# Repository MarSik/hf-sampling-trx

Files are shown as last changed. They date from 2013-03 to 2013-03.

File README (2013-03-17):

HF RX based on QSD and class E TX
---------------------------------

Important components:

Si570 - any frequency I2C controlled square wave oscillator
74CBT(LV)3253 - dual 1:4 analog multiplexor
LT6231CS8 - ultra low noise (1.1nV/sqrtHz) opamp
ATXmega128A3U - 8bit micro with dual ADC and DAC
XC9572XL - CPLD, programmable logic, 3.3V

References:

- Dan Tayloe, N7VE
  Ultra Low Noise, High Performance, Zero IF Quadrature Product Detector and Preamplifier
  http://www.norcalqrp.org/files/Tayloe_mixer_x3a.pdf

- Gerald Youngblood, AC5OG
  A Software-Defined Radio for the Masses
  http://www.flex-radio.com/data/doc/qex1.pdf
  http://www.flex-radio.com/data/doc/qex2.pdf
  http://www.flex-radio.com/data/doc/qex3.pdf
  http://www.flex-radio.com/data/doc/qex4.pdf

- YU1LM
  HF - 6m band pass filters
  http://yu1lm.qrpradio.com/HF-6m%20BP%20YU1LM%20ver2.pdf

- Dan Tayloe, N7VE
  Class E Amplifiers - NorCal QRP Club
  http://www.norcalqrp.org/files/class_e_amplifiers.pdf

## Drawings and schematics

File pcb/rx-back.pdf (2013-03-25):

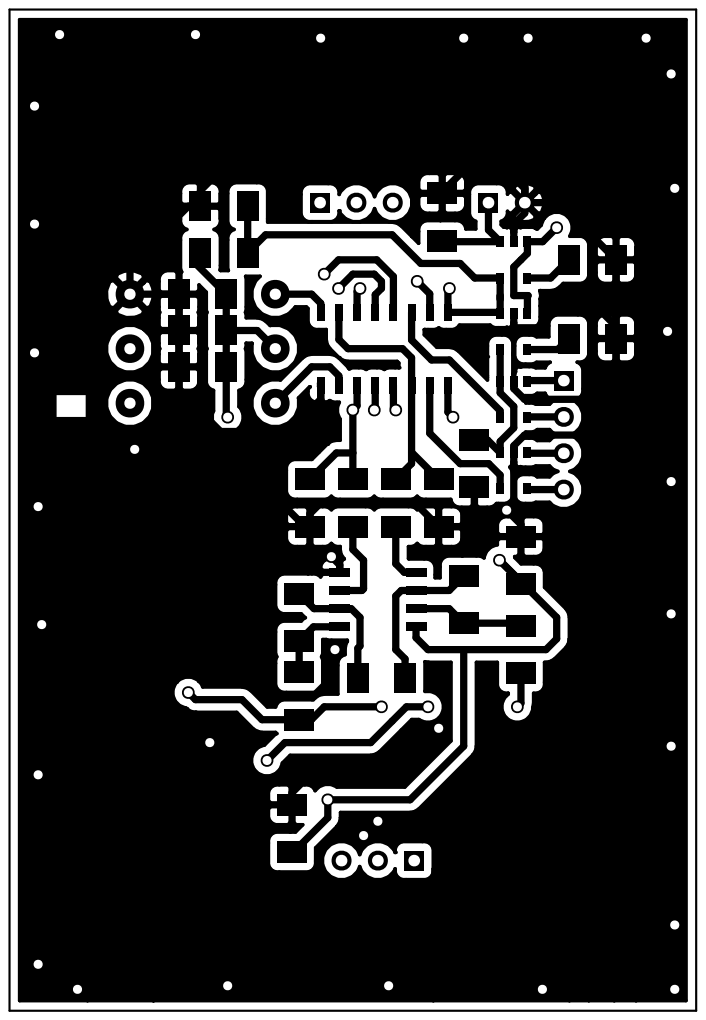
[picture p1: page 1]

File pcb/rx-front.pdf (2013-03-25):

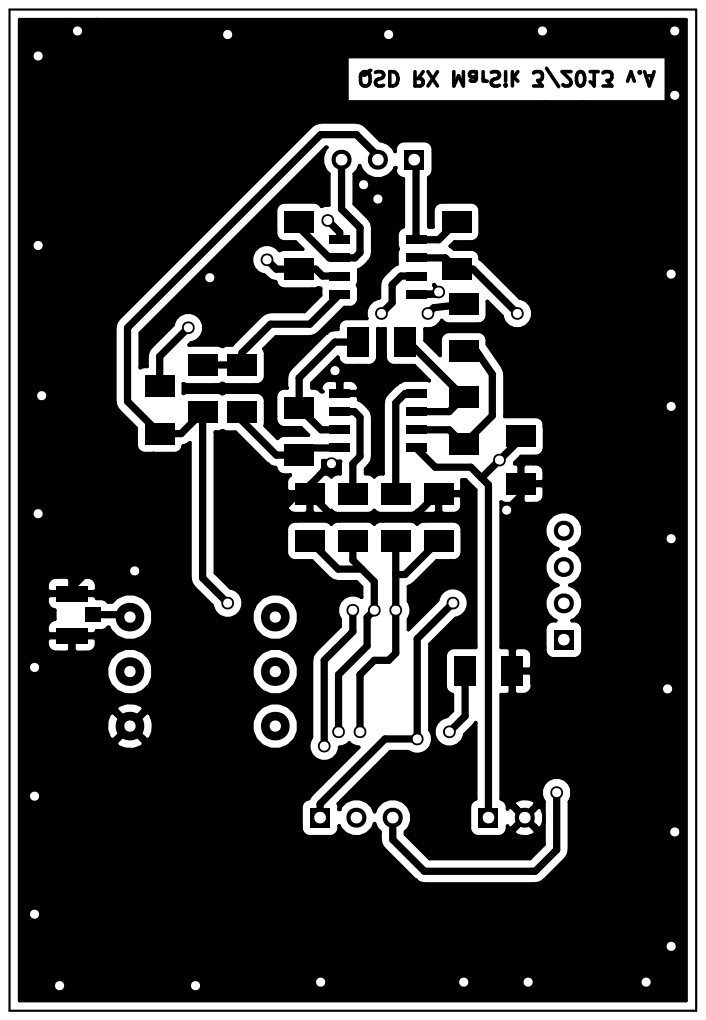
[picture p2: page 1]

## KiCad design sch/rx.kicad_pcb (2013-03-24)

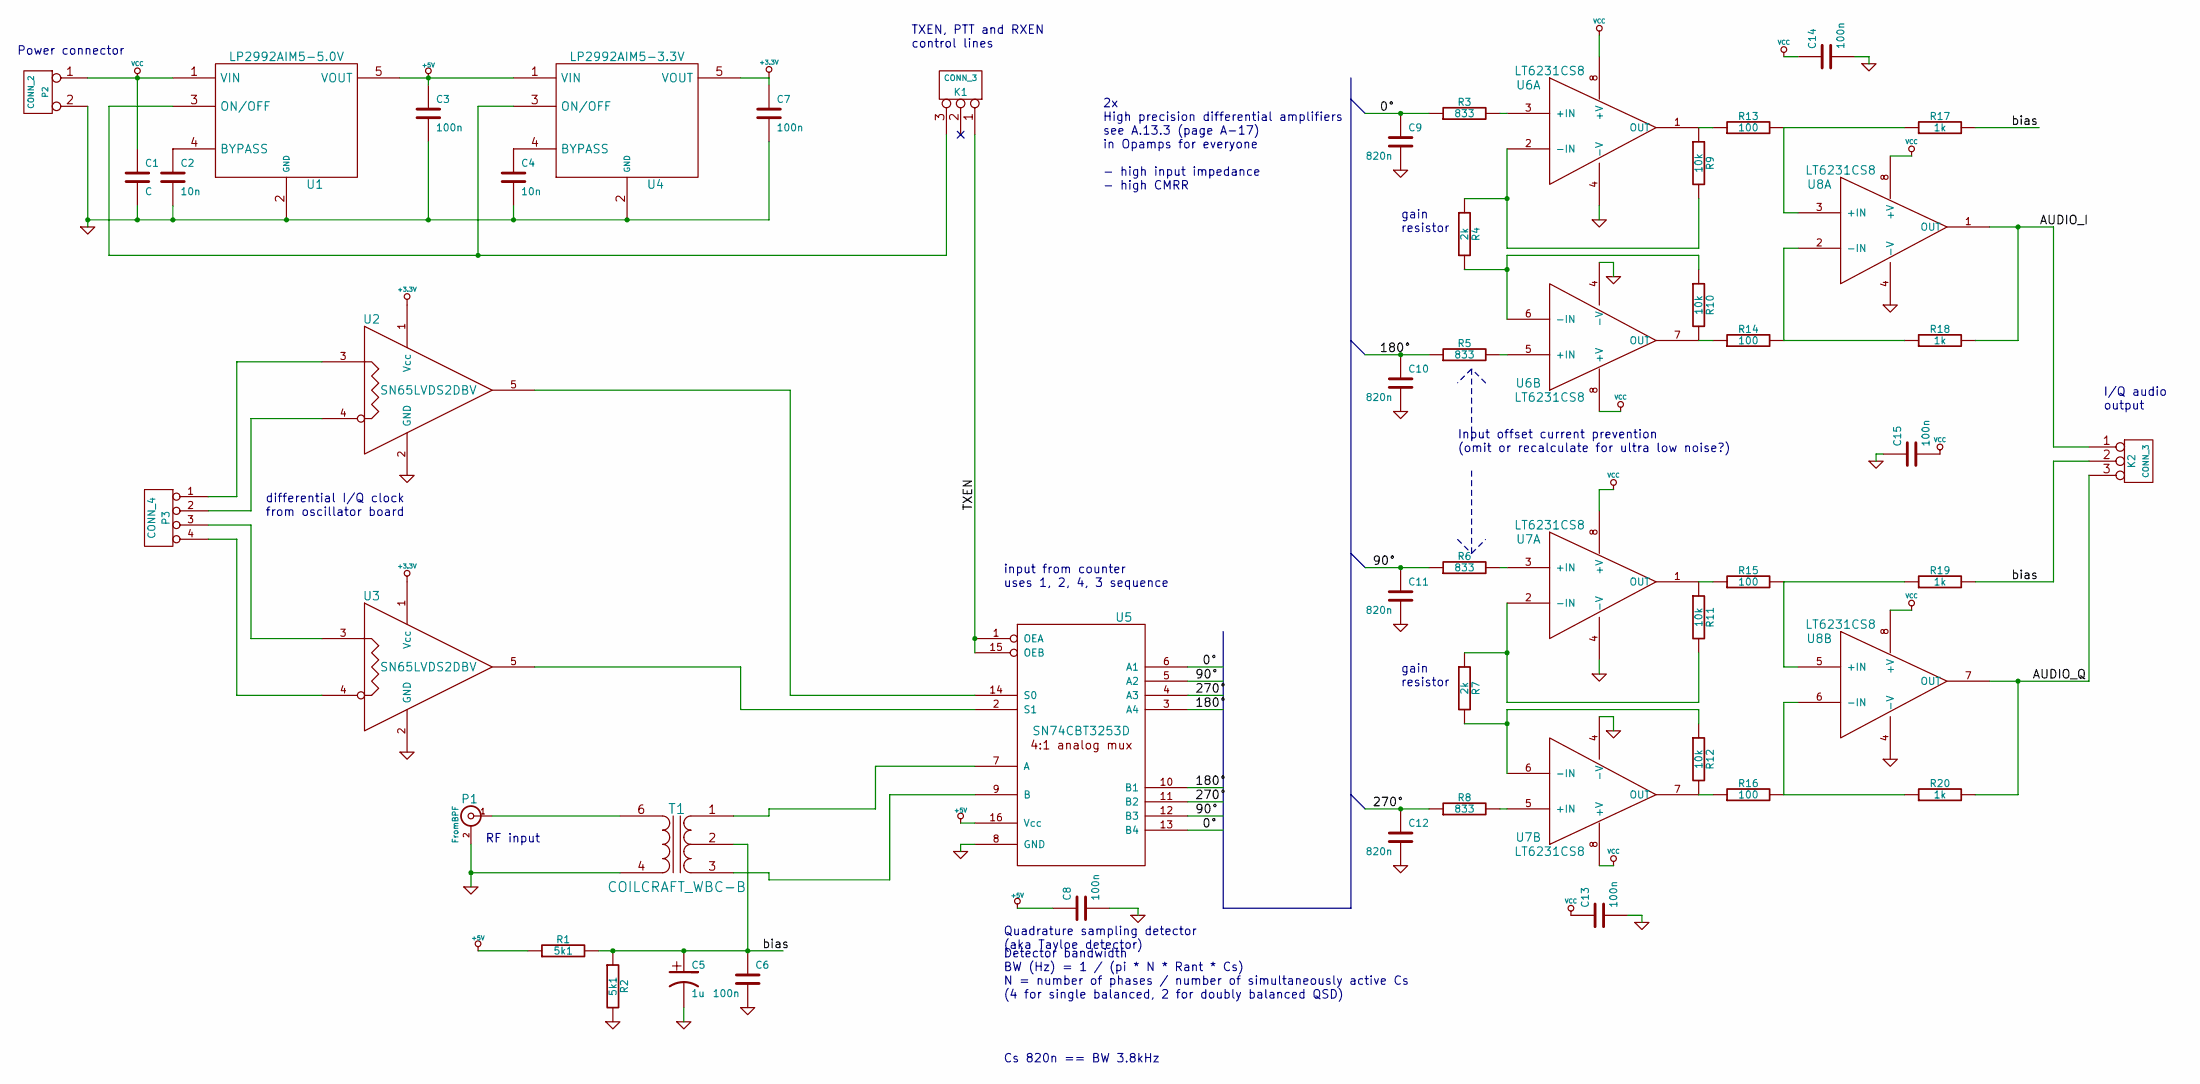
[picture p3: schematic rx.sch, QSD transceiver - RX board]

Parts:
C1: C
C2, C4: 10n
C3, C6, C7, C8, C13, C14, C15: 100n
C5: 1u
C9, C10, C11, C12: 820n
K1, K2: CONN_3
P1: FromBPF
P2: CONN_2
P3: CONN_4
R1, R2: 5k1
R3, R5, R6, R8: 833
R4, R7: 2k
R9, R10, R11, R12: 10k
R13, R14, R15, R16: 100
R17, R18, R19, R20: 1k
T1: COILCRAFT_WBC-B
U1: LP2992AIM5-5.0V; SOT23-5; Part Number LP2992AIM5-3.3CT-ND
U2, U3: SN65LVDS2DBV
U4: LP2992AIM5-3.3V; SOT23-5; Part Number LP2992AIM5-3.3CT-ND
U5: SN74CBT3253D
U6, U7, U8: LT6231CS8

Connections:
+3.3V: C7.1, U2.1 (Vcc), U3.1 (Vcc), U4.5 (VOUT)
+5V: C3.1, C8.1, R1.1, U1.5 (VOUT), U4.1 (VIN), U5.16 (Vcc)
/0°: C9.1, R3.1, U5.6 (A1), U5.13 (B4)
/90°: C11.1, R6.1, U5.5 (A2), U5.12 (B3)
/180°: C10.1, R5.1, U5.3 (A4), U5.10 (B1)
/270°: C12.1, R8.1, U5.4 (A3), U5.11 (B2)
/AUDIO_I: K2.1, R18.2, U8.1 (OUT)
/AUDIO_Q: K2.3, R20.2, U8.7 (OUT)
/TXEN: K1.1, U5.1 (OEA), U5.15 (OEB)
/bias: C5.1, C6.1, K2.2 (PM), R1.2, R2.1, R17.2, R19.2, T1.2 (PM)
GND: C1.2, C2.2, C3.2, C4.2, C5.2, C6.2, C7.2, C8.2, C9.2, C10.2, C11.2, C12.2, C13.2, C14.2, C15.1, P1.2 (Ext), P2.2 (PM), R2.2, T1.4 (S1), U1.2 (GND), U2.2 (GND), U3.2 (GND), U4.2 (GND), U5.8 (GND), U6.4 (-V), U7.4 (-V), U8.4 (-V)
unnamed: T1.1 (PR1), U5.7 (A)
unnamed: R16.2, R20.1, U8.6 (-IN)
unnamed: R15.2, R19.1, U8.5 (+IN)
unnamed: R7.2, R12.1, U7.6 (-IN)
unnamed: R11.1, R15.1, U7.1 (OUT)
unnamed: R12.2, R16.1, U7.7 (OUT)
unnamed: R5.2, U6.5 (+IN)
unnamed: R13.2, R17.1, U8.3 (+IN)
unnamed: R10.2, R14.1, U6.7 (OUT)
unnamed: C2.1, U1.4 (BYPASS)
unnamed: R4.2, R10.1, U6.6 (-IN)
unnamed: R3.2, U6.3 (+IN)
unnamed: R9.1, R13.1, U6.1 (OUT)
unnamed: R14.2, R18.1, U8.2 (-IN)
unnamed: R4.1, R9.2, U6.2 (-IN)
unnamed: P3.4, U3.4
unnamed: P3.3, U3.3
unnamed: P3.1, U2.3
unnamed: P3.2, U2.4
unnamed: U2.5, U5.14 (S0)
unnamed: P1.1 (In), T1.6 (S2)
unnamed: R8.2, U7.5 (+IN)
unnamed: R6.2, U7.3 (+IN)
unnamed: R7.1, R11.2, U7.2 (-IN)
unnamed: U3.5, U5.2 (S1)
unnamed: K1.3, U1.3 (ON/OFF), U4.3 (ON/OFF)
unnamed: T1.3 (PR2), U5.9 (B)
unnamed: C4.1, U4.4 (BYPASS)
VCC: C1.1, C13.1, C14.1, C15.2, P2.1, U1.1 (VIN), U6.8 (+V), U7.8 (+V), U8.8 (+V)

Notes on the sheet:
Quadrature sampling detector (aka Tayloe detector)
gain resistor
Input offset current prevention (omit or recalculate for ultra low noise?)
2x High precision differential amplifiers see A.13.3 (page A-17) in Opamps for everyone - high input impedance - high CMRR
input from counter uses 1, 2, 4, 3 sequence
differential I/Q clock from oscillator board
Power connector
RF input
I/Q audio output
TXEN, PTT and RXEN control lines
Detector bandwidth BW (Hz) = 1 / (pi * N * Rant * Cs) N = number of phases / number of simultaneously active Cs (4 for single balanced, 2 for doubly balanced QSD)
Cs 820n == BW 3.8kHz

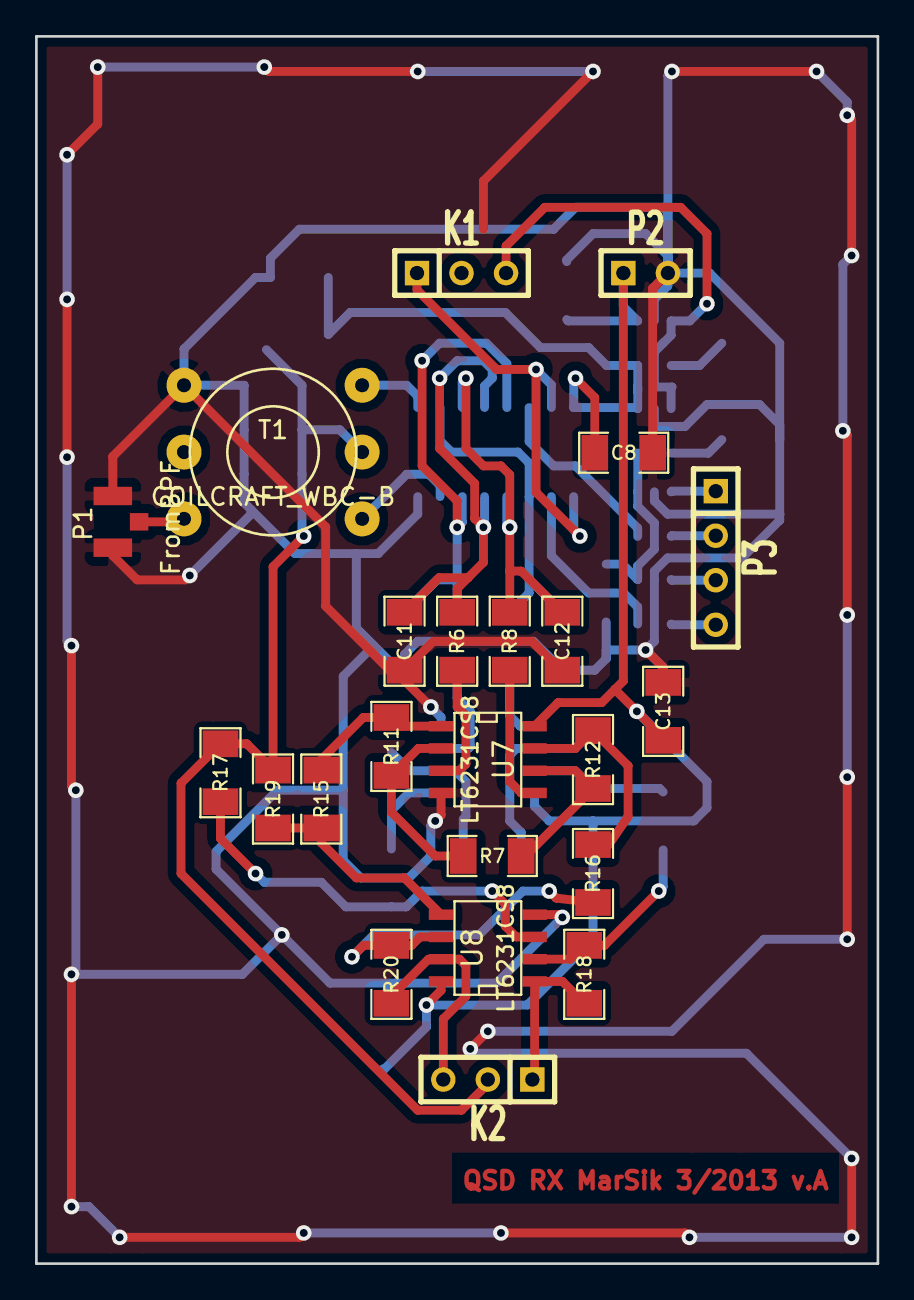
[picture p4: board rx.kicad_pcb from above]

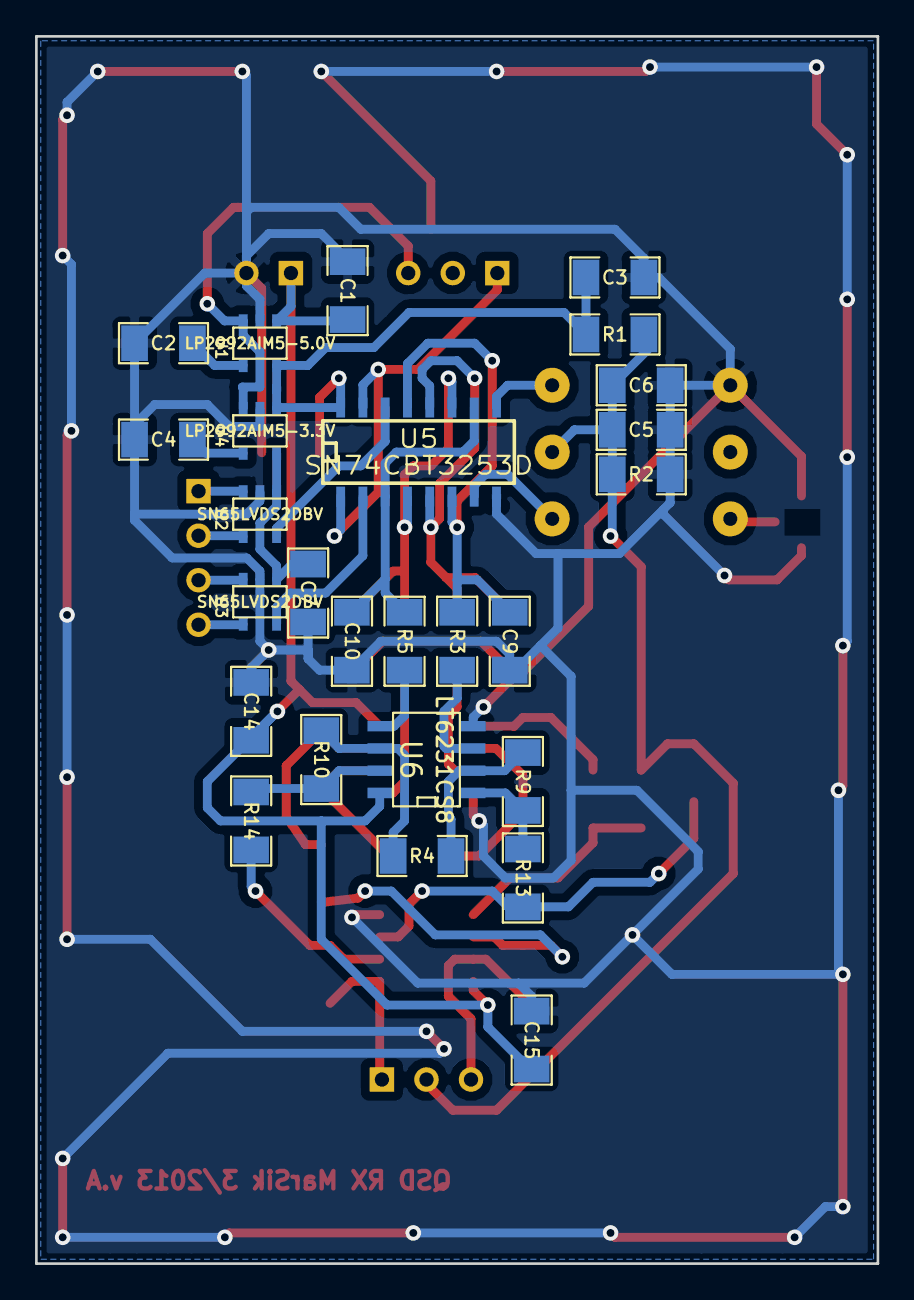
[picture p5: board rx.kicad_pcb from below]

Board: 2 copper layers, 48.0 x 70.0 mm, 49 parts (26 on the bottom side), 40 nets.

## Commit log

2012-06-30 Inital version
    [bpf.sch, clock.sch, cpulcd.sch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]
2012-06-30 add FIN1002 buffer for LVDS variant of Si570
    [bpf.sch, clock.sch, cpulcd.sch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]
2012-11-26 Split the RX, TX, CPU and interface boards + make the TRX more modular
    [cpu.sch, hf-sampling-trx.sch, lcd_rotary.sch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]
2013-03-17 Add models and updated schematics
    [audio.sch, bpf.sch, clock.sch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]
2013-03-24 Prototype RX pcb
    [rx.kicad_pcb, rx.sch]
2013-03-24 Fill more board space with ground in RX
    [rx.kicad_pcb]
2013-03-25 Gerber and pdf files for RX board (for manufacturing at home)
    [rx-B_Cu.gbl, rx-B_SilkS.gbo, rx-Edge_Cuts.gbr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]
2013-03-25 Add capacitors to RX board schematics
    [rx.sch]
